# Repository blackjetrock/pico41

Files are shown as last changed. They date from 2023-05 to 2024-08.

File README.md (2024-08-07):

This project has been superseded by Tulip
=========================================

It is recommeded that the Tulip project is used instead of this one. It can be found here:

https://github.com/mjakuipers/TULIP-DevBoard

It has more features, by far. The only feature that it doesn't have is the key pressing, but it does have many more ways to enter programs...

Pico41
======

This is a PCB that can be attached to an HP41C (using wires soldered to the processor PCB of the HP41C) that allows:

* The HP41C bus to be examined and traced
* Data to be placed on the bus
* Keys on the keyboard to be pressed
* viewing of the display on an OLED display on the PCB

You can see what is happening on the bus just like a logic analyser. The tracing (and other interaction) is through the USB of the Pico.
You can emulate modules by putting appropriate words on the bus. Currently I have emulated a MATH module. Bank switched modules aren't supported, nor are RAM modules, but that is just a matter of code that I haven't done yet.
You can press keys on the keyboard, so can enter programs by pressing the appropriate keys. I have a script that converts program in text form and embeds the keypresses into the Pico program such that they can be played back in PRGM mode. Once entered like this the program can be SST'd automatically and checked against a listing that is also embedded in the Pio program.

RP Pico on HP41C bus, showing an emulated MATH module where one word has been altered:

IMAG3808

To Do
=====

It should be possible to emulate the display controller and use this Pico setup as a replacement for the display controller. For example a broken display controller should be replaceable by this program.
RAM should also be emulatable with more code.
Module code could be changed over USB rather than being embedded in the Pico code as it is now.

More Information
================

* https://youtu.be/KFQwrbWywjY
* https://youtu.be/kRxo2ekzvyg

This is a work in progress
==========================

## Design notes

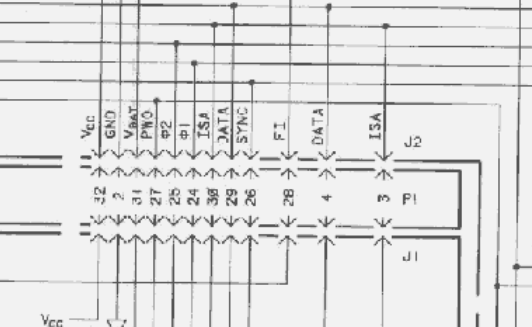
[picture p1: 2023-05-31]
pcb/Screenshot_20220318_142952.png

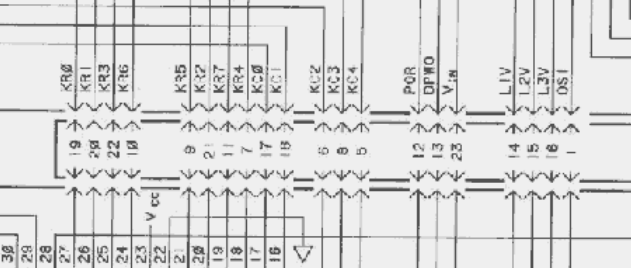
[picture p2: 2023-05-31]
pcb/Screenshot_20220318_143427.png

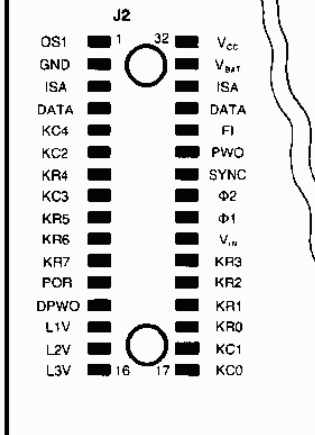
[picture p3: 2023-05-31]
pcb/Screenshot_20220318_143222.png

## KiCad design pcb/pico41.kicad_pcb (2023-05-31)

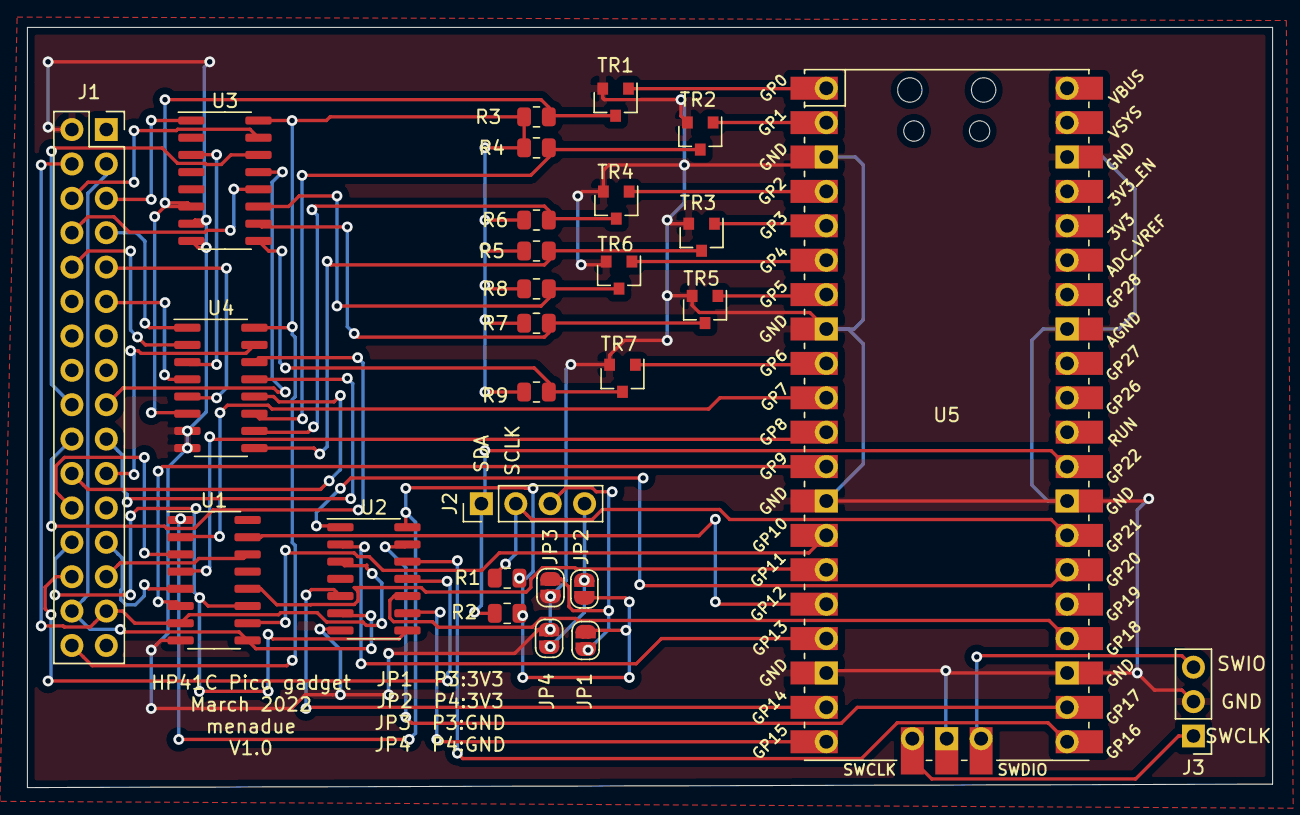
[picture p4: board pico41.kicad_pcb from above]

Board: 2 copper layers, 91.9 x 56.1 mm, 28 parts (0 on the bottom side), 57 nets.

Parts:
J1: Conn_02x16_Counter_Clockwise; PinSocket_2x16_P2.54mm_Vertical
J2: Conn_01x04_Female; PinHeader_1x04_P2.54mm_Vertical
J3: Conn_01x03_Female; PinHeader_1x03_P2.54mm_Vertical
JP1, JP2, JP3, JP4: Jumper_NO_Small; SolderJumper-2_P1.3mm_Open_RoundedPad1.0x1.5mm
R1, R2: 4k7; R_0805_2012Metric
R3, R4, R5, R6, R7, R8, R9: 10k; R_0805_2012Metric
TR1: Si2302; SOT-23
TR2, TR3, TR4, TR5, TR6, TR7: si2302; SOT-23
U1: 4050; SOIC-16_3.9x9.9mm_P1.27mm
U2: 74LS125; SOIC-14_3.9x8.7mm_P1.27mm
U3, U4: 4051; SOIC-16_3.9x9.9mm_P1.27mm
U5: Pico; RPi_Pico_SMD_TH

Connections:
3V3: JP1.1, JP2.1, R1.1, R2.1, U1.1, U2.14
DATA: J1.4, J1.29, U1.7, U2.3
FI: J1.28, U2.11
GND: J1.2, J3.2, JP3.1, JP4.1, TR1.2, TR2.2, TR3.2, TR4.2, TR5.2, TR6.2, TR7.2, U1.8, U2.7, U3.7, U3.8, U4.7, U4.8, U5.3, U5.8, U5.13, U5.18, U5.23, U5.28, U5.33, U5.38, U5.42
I2C_SCL: J2.2, R1.2, U5.27
I2C_SDA: J2.1, R2.2, U5.29
ISA: J1.3, J1.30, U1.9, U2.6
KB_INH: R3.2, TR1.3, U3.6, U4.6
KC0: J1.17, U3.13
KC1: J1.18, U3.14
KC2: J1.6, U3.15
KC3: J1.8, U3.12
KC4: J1.5, U3.1
KCA: R8.2, TR6.3, U3.11
KCB: R7.2, TR5.3, U3.10
KCC: R9.2, TR7.3, U3.9
KR0: J1.19, U4.13
KR1: J1.20, U4.14
KR2: J1.21, U4.15
KR3: J1.22, U4.12
KR4: J1.7, U4.1
KR5: J1.9, U4.5
KR6: J1.10, U4.2
KR7: J1.11, U4.4
KRA: R4.2, TR2.3, U4.11
KRB: R6.2, TR4.3, U4.10
KRC: R5.2, TR3.3, U4.9
unnamed: J2.3, JP1.2, JP3.2
unnamed: J2.4, JP2.2, JP4.2
unnamed: U3.3, U4.3
PHI1: J1.24, U1.3
PHI2: J1.25, U1.5
PWO: J1.27, U1.14
P_DATA: U1.6, U5.12
P_DATA_DRV: U2.2, U5.17
P_DATA_OE: U2.1, U5.26
P_FI_DRV: U2.12, U5.21
P_FI_OE: U2.13, U5.22
P_ISA: U1.10, U5.14
P_ISA_DRV: U2.5, U5.19
P_KB_INH: TR1.1, U5.1
P_KCA: TR6.1, U5.6
P_KCB: TR5.1, U5.7
P_KCC: TR7.1, U5.9
P_KRA: TR2.1, U5.2
P_KRB: TR4.1, U5.4
P_KRC: TR3.1, U5.5
P_PHI1: U1.2, U5.10
P_PHI2: U1.4, U5.11
P_PWO: U1.15, U5.16
P_SYNC: U1.12, U5.15
P_SYNC_DRV: U2.9, U5.20
P_SYNC_OE: U2.10, U5.24
SWCLK: J3.1, U5.41
SWIO: J3.3, U5.43
SYNC: J1.26, U1.11, U2.8
VCC: J1.32, R3.1, R4.1, R5.1, R6.1, R7.1, R8.1, R9.1, U3.16, U4.16

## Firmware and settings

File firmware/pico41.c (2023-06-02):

/*
 * HP41C monitoring and control from Pico
 *
 */

#include <ctype.h>
#include <stdio.h>
#include <string.h>
#include <stdlib.h>
#include <stdint.h>

#include "pico/stdlib.h"
//#include "hardware/i2c.h"
#include "hardware/gpio.h"
#include "hardware/pio.h"
#include "hardware/clocks.h"
#include "pico/multicore.h"

////////////////////////////////////////////////////////////////////////////////
//
// Configuration flags
//

#define CF_DUMP_DBG_DREGS  0
#define CF_DISPLAY_LCD     1
#define CF_DISPLAY_OLED    1
#define CF_DBG_DISP_ON     0
#define CF_DBG_SLCT        0
#define CF_DBG_DISP_INST   0
#define CF_USE_DISP_ON     1
#define CF_DBG_KEY         1

// Do we allow embedded ROM to be seen on the bus?

#define EMBED_8000_ROM     1
#define EMBED_9000_ROM     1

#define MAX_KWB  50

#define PRESS_DELAY_1   50
#define PRESS_DELAY_2   2000

////////////////////////////////////////////////////////////////////////////////
//
// GPIO Pins
//

const uint P_KB_INH            = 0;
const uint P_KRA               = 1;
const uint P_KRB               = 2;
const uint P_KRC               = 3;

const uint P_KCA               = 4;
const uint P_KCB               = 5;
const uint P_KCC               = 6;

const uint P_CLK1              = 7;
const uint P_CLK2              = 8;

const uint P_DATA              = 9;
const uint P_ISA               = 10;
const uint P_SYNC              = 11;
const uint P_PWO               = 12;
const uint P_DATA_DRV          = 13;
const uint P_ISA_DRV           = 14;
const uint P_SYNC_DRV          = 15;
const uint P_FI_DRV            = 16;
const uint P_FI_OE             = 17;
const uint P_SYNC_OE           = 18;
const uint P_ISA_OE            = 19;
const uint P_DATA_OE           = 20;

// For the OLED display
const uint SDA_PIN             = 22;
const uint SCL_PIN             = 21;

volatile int core1_command = 0;

#ifndef I2C_FUNCTIONS_H_
#define I2C_FUNCTIONS_H_

typedef unsigned char BYTE;

// I2C Port descriptor
typedef struct _I2C_PORT_DESC
{
  unsigned char sdaport;
  unsigned char sdabit;
  unsigned char sclport;
  unsigned char sclbit;
} I2C_PORT_DESC;


// Slave device descriptor
typedef struct _I2C_SLAVE_DESC
{
  I2C_PORT_DESC *port;             // Port the device is on
  unsigned char slave_7bit_addr;        // SLave address
} I2C_SLAVE_DESC;


// I2C functions
void i2c_release(I2C_PORT_DESC *port);
void i2c_delay(I2C_PORT_DESC *port);
void i2c_sda_low(I2C_PORT_DESC *port);
void i2c_sda_high(I2C_PORT_DESC *port);
void i2c_scl_low(I2C_PORT_DESC *port);
void i2c_scl_high(I2C_PORT_DESC *port);
void i2c_start(I2C_PORT_DESC *port);
void i2c_stop(I2C_PORT_DESC *port);
int i2c_send_byte(I2C_PORT_DESC *port, BYTE b);
int i2c_read_bytes(I2C_SLAVE_DESC *slave, int n, BYTE *data);
void i2c_send_bytes(I2C_SLAVE_DESC *slave, int n, BYTE *data);
#


#endif /* I2C_FUNCTIONS_H_ */

// Memory that emulates a pak
typedef unsigned char BYTE;
typedef void (*FPTR)(void);
typedef void (*CMD_FPTR)(char *cmd);


// Serial loop command structure
typedef struct
{
  char key;
  char *desc;
  FPTR fn;
} SERIAL_COMMAND;

////////////////////////////////////////////////////////////////////////////////
//
// HP41C stuff
//
////////////////////////////////////////////////////////////////////////////////

// Bus instructions
// Beware: These are in octal

#define INST_DISPLAY_OFF               01340
#define INST_DISPLAY_TOGGLE            01440
#define INST_COMPENSATION_INSTRUCTION  01774
#define INST_C_PFAD                    01760
#define INST_WRITE_ANNUNCIATORS        01360
#define INST_READ_ANNUNCIATORS         00570
#define INST_SRLAD                     00050
#define INST_SRLDB                     00150
#define INST_SRLDC                     00250
#define INST_SRLDAB                    00350
#define INST_SRLDABC                   00450
#define INST_SLLDAB                    00550
#define INST_SLLDABC                   00650
#define INST_SRSDA                     00750
#define INST_SRSDB                     01050
#define INST_SRSDC                     01150
#define INST_SLSDA                     01250
#define INST_SLSDB                     01350
#define INST_SRSDAB                    01450
#define INST_SLSDAB                    01550
#define INST_SRSDABC                   01650
#define INST_SLSDABC                   01750
#define INST_PRPH_SLCT                 01760
#define INST_RAM_SLCT                  01160

#define INST_FLLDA                     00070
#define INST_FLLDB                     00170
#define INST_FLLDC                     00270
#define INST_FLLDAB                    00370
#define INST_FLLDABC                   00470
#define INST_FLSDC                     00670
#define INST_FRSDA                     00770
#define INST_FRSDB                     01070
#define INST_FRSDC                     01170
#define INST_FLSDA                     01270
#define INST_FLSDB                     01370
#define INST_FRSDAB                    01470
#define INST_FLSDAB                    01570
#define INST_FRSDABC                   01670
#define INST_FLSDABC                   01770

// bank switching instructions
#define INST_ENBANK1                   0x100
#define INST_ENBANK2                   0x180
#define INST_ENBANK3                   0x140
#define INST_ENBANK4                   0x1C0

#define INST_ENROM1                    0x1500
#define INST_ENROM2                    0x1980
#define INST_ENROM3                    0x1D40
#define INST_ENROM4                    0x1C0



#define MASK_48_BIT    (0xFFFFFFFFFFFFL)

int display_ce = 0;
char dtext[40];

#define ROTATE_RIGHT(V) {uint64_t t = (V & 0xF); V >>= 4; V |= t<<44;}
#define  ROTATE_LEFT(V) {uint64_t t = (V & (0xFLL << 44)); V <<= 4; V |= t>>44;}

////////////////////////////////////////////////////////////////////////////////
//
// Prototypes
//
//

void process_bus(void);

////////////////////////////////////////////////////////////////////////////////

// Where embedded ROM image is located
#define LOW_EMBED_ROM_ADDR   0x8000
#define HIGH_EMBED_ROM_ADDR  0x8FFF

#define LOW_EMBED_ROM2_ADDR   0x9000
#define HIGH_EMBED_ROM2_ADDR  0x9FFF

// Do we drive ROM data?
int drive_data_flag = 0;

// The data we drive
int drive_data = 0;

// How many times have we driven ISA?
volatile int driven_isa = 0;
volatile int embed_seen = 0;
volatile int sync_count = 0;

char *embed_prog[] = {
		      // HP41C_EMBEDDED_PROG_START
"01 LBLGPHASE", "02 DEG", "03 XEQGJ0", "04 7.382647", "05 STO 03", "06 /", "07 INT", "08 STO 06", 
"09 ST* 03", "10 4", "11 MOD", "12 STO 04", "13 2", "14 STO 02", "15 XMY?", "16 ST- 02", 
"17 ST/ 02", "18 MOD", "19 STO 05", "20 221", "21 *", "22 RCL 02", "23 -", "24 407", 
"25 +", "26 RCL 06", "27 96.45423", "28 *", "29 21.6", "30 +", "31 STO 00", "32 SIN", 
"33 *", "34 RCL 06", "35 7.2763", "36 *", "37 2.6", "38 +", "39 STO 01", "40 SIN", 
"41 172", "42 RCL 02", "43 +", "44 *", "45 +", "46 RCL 05", "47 7", "48 *", 
"49 16", "50 -", "51 RCL 00", "52 ST+ X", "53 SIN", "54 *", "55 -", "56 RCL 05", 
"57 5", "58 -", "59 ST+ X", "60 RCL 06", "61 195.335", "62 *", "63 39", "64 -", 
"65 STO 02", "66 SIN", "67 *", "68 -", "69 RCL 05", "70 ST+ X", "71 7", "72 -", 
"73 RCL 00", "74 RCL 01", "75 -", "76 SIN", "77 *", "78 +", "79 RCL 05", "80 7", 
"81 *", "82 5", "83 +", "84 RCL 00", "85 RCL 01", "86 +", "87 SIN", "88 *", 
"89 +", "90 RCL 01", "91 ST+ X", "92 SIN", "93 ST+ X", "94 +", "95 RCL 05", "96 RCL 00", 
"97 RCL 02", "98 -", "99 SIN", "100 ST* Y", "101 +", "102 +", "103 RCL 04", "104 90", 
"105 *", "106 SIN", "107 3", "108 *", "109 +", "110 5598", "111 +", "112 E3", 
"113 /", "114 RCL 03", "115 +", "116 INT", "117 LASTX", "118 FRC", "119 X<0?", "120 DSE Y", 
"121 """, "122 24", "123 ST* Y", "124 MOD", "125 HMS", "126 X<>Y", "127 XEQGDT", "128 RCL 04", 

// HP41C_EMBEDDED_PROG_END
};

char *embed_keys[] = {
// HP41C_EMBEDDED_KEYS_START
"SHIFT", "STO", "ALPHA", "P", "H", "A", "S", "E", 
"ALPHA", "XEQ", "ALPHA", "D", "E", "G", "ALPHA", "XEQ", 
"ALPHA", "J", "SHIFT", "0", "ALPHA", "7", ".", "3", 
"8", "2", "6", "4", "7", "STO", "0", "3", 
"/", "XEQ", "ALPHA", "I", "N", "T", "ALPHA", "STO", 
"0", "6", "STO", "*", "0", "3", "4", "XEQ", 
"ALPHA", "M", "O", "D", "ALPHA", "STO", "0", "4", 
"2", "STO", "0", "2", "XEQ", "ALPHA", "X", "SHIFT", 
"H", "Y", "3", "ALPHA", "STO", "-", "0", "2", 
"STO", "/", "0", "2", "XEQ", "ALPHA", "M", "O", 
"D", "ALPHA", "STO", "0", "5", "2", "2", "1", 
"*", "RCL", "0", "2", "-", "4", "0", "7", 
"+", "RCL", "0", "6", "9", "6", ".", "4", 
"5", "4", "2", "3", "*", "2", "1", ".", 
"6", "+", "STO", "0", "0", "SIN", "*", "RCL", 
"0", "6", "7", ".", "2", "7", "6", "3", 
"*", "2", ".", "6", "+", "STO", "0", "1", 
"SIN", "1", "7", "2", "RCL", "0", "2", "+", 
"*", "+", "RCL", "0", "5", "7", "*", "1", 
"6", "-", "RCL", "0", "0", "STO", "+", ".", 
"X", "SIN", "*", "-", "RCL", "0", "5", "5", 
"-", "STO", "+", ".", "X", "RCL", "0", "6", 
"1", "9", "5", ".", "3", "3", "5", "*", 
"3", "9", "-", "STO", "0", "2", "SIN", "*", 
"-", "RCL", "0", "5", "STO", "+", ".", "X", 
"7", "-", "RCL", "0", "0", "RCL", "0", "1", 
"-", "SIN", "*", "+", "RCL", "0", "5", "7", 
"*", "5", "+", "RCL", "0", "0", "RCL", "0", 
"1", "+", "SIN", "*", "+", "RCL", "0", "1", 
"STO", "+", ".", "X", "SIN", "STO", "+", ".", 
"X", "+", "RCL", "0", "5", "RCL", "0", "0", 
"RCL", "0", "2", "-", "SIN", "STO", "*", ".", 
"Y", "+", "+", "RCL", "0", "4", "9", "0", 
"*", "SIN", "3", "*", "+", "5", "5", "9", 
"8", "+", "1", "EEX", "3", "/", "RCL", "0", 
"3", "+", "XEQ", "ALPHA", "I", "N", "T", "ALPHA", 
"XEQ", "ALPHA", "L", "A", "S", "T", "X", "ALPHA", 
"XEQ", "ALPHA", "F", "R", "C", "ALPHA", "XEQ", "ALPHA", 
"X", "SHIFT", "I", "SHIFT", "0", "3", "ALPHA", "XEQ", 
"ALPHA", "D", "S", "E", "ALPHA", ".", "Y", "XEQ", 
"ALPHA", "N", "O", "P", "ALPHA", "2", "4", "STO", 
"*", ".", "Y", "XEQ", "ALPHA", "M", "O", "D", 
"ALPHA", "XEQ", "ALPHA", "H", "M", "S", "ALPHA", "X<>Y", 
"XEQ", "ALPHA", "D", "T", "ALPHA", "RCL", "0", "4", 

// HP41C_EMBEDDED_KEYS_END
};

// Byte grabber keystrokes
char *byte_grabber_keys[] =
  {
#if 1
   "SHIFT","XEQ", "ALPHA", "SHIFT", "+", "ALPHA", "LN",
   "WAIT1",
   "SHIFT","XEQ", "ALPHA", "D", "E", "L", "ALPHA", "LOG",
   "WAIT1",
#endif   
   "PRGM",
   "WAIT1",
   "SHIFT",
   "WAIT1",
   "ENTER",
   "WAIT1",
   "1",
   "WAIT2",
   "R/S",
   "ALPHA",
   "<-",
   "ALPHA",
   "SHIFT", "RCL", ".", "0", "0", "5",
#if 0
   "USER",
   "LOG", "0", "0", "3",
   "ALPHA",
   "3", "A", "A", "A", "A", "A", "A",
   "PRGM", "ALPHA",
   "SHIFT", "RCL", ".", "."
#endif
  };

// Embedded ROM images

int embed_zenrom_rom[] = {
		   
0x0005,0x000d,0x0000,0x0028,0x0005,0x0079,0x0005,0x0090,0x0005,0x0010,0x0004,0x00aa,0x0005,0x0069,0x0005,0x00cc,
0x0005,0x0029,0x0004,0x00ce,0x0004,0x00d6,0x0004,0x00de,0x0003,0x0047,0x0005,0x0042,0x0000,0x0000,0x0082,0x0033,
0x0020,0x000d,0x000f,0x0012,0x000e,0x0005,0x001a,0x002d,0x03e0,0x005e,0x027e,0x0398,0x00ee,0x004e,0x029c,0x0210,
0x0158,0x010e,0x03f8,0x03b0,0x010e,0x0198,0x028c,0x01af,0x034e,0x01a3,0x02ae,0x010e,0x03f8,0x03b0,0x03e8,0x0198,
0x010e,0x02b8,0x03b0,0x010e,0x03b8,0x02bc,0x03d8,0x0384,0x034e,0x0013,0x0388,0x03d8,0x02bc,0x03a8,0x0198,0x02ae,
0x010e,0x02b8,0x03b0,0x02a8,0x00ee,0x0358,0x02fe,0x00e1,0x003e,0x023e,0x01df,0x03b8,0x031c,0x0171,0x001c,0x0278,
0x0325,0x0050,0x0268,0x02b8,0x003c,0x0106,0x0130,0x000f,0x036a,0x002f,0x0229,0x001a,0x007b,0x0153,0x0086,0x03d9,
0x001c,0x03dd,0x00ac,0x0149,0x0024,0x0278,0x00e0,0x02dc,0x00a0,0x0171,0x003e,0x034e,0x00df,0x010e,0x03f8,0x0370,
0x03e8,0x02b8,0x010e,0x0198,0x00ee,0x03b8,0x02bc,0x03d8,0x00ee,0x038c,0x0027,0x02ae,0x03b0,0x0017,0x0370,0x02a8,
0x00ce,0x0384,0x03d8,0x02bc,0x03a8,0x0171,0x001c,0x004e,0x01b0,0x0170,0x010e,0x015c,0x0010,0x0350,0x03d0,0x0290,
0x036e,0x01d7,0x0020,0x00b0,0x03cd,0x009c,0x0049,0x0036,0x0130,0x0020,0x03a8,0x03a8,0x03a8,0x00e6,0x036d,0x007c,
0x0106,0x001e,0x0130,0x0054,0x0366,0x0025,0x003a,0x02dc,0x00d0,0x0130,0x005b,0x017e,0x0266,0x0366,0x03bb,0x037e,
0x03df,0x02dc,0x0290,0x0130,0x004c,0x017e,0x0366,0x0373,0x0226,0x017e,0x037e,0x03df,0x0366,0x002f,0x0130,0x007f,
0x0106,0x0323,0x0130,0x0040,0x017e,0x003f,0x0226,0x0366,0x03e7,0x0126,0x02db,0x00d3,0x0086,0x0130,0x0007,0x0106,
0x0149,0x0024,0x03f8,0x003c,0x03b0,0x0366,0x002b,0x03d9,0x001c,0x0079,0x003a,0x0066,0x0130,0x002c,0x0366,0x03c7,
0x02b8,0x003c,0x010e,0x0265,0x0036,0x009c,0x0350,0x0090,0x0090,0x036e,0x00d7,0x02b8,0x003c,0x0056,0x02e6,0x003b,
0x03f8,0x003c,0x03d8,0x038c,0x002f,0x03d8,0x00b0,0x03cd,0x009e,0x0304,0x0204,0x03d8,0x01bc,0x03e8,0x0020,0x00d1,
0x0030,0x0000,0x03ad,0x0032,0x009c,0x0350,0x0310,0x0110,0x036e,0x0087,0x0020,0x00b0,0x03cd,0x009c,0x0049,0x0036,
0x005c,0x0210,0x00d0,0x011a,0x0220,0x037a,0x0315,0x0037,0x00cb,0x009c,0x0310,0x0390,0x0350,0x036e,0x012f,0x0020,
0x00b0,0x03cd,0x009c,0x0049,0x0036,0x028c,0x03cd,0x0037,0x005c,0x0210,0x00d0,0x011a,0x031c,0x0220,0x037a,0x03b9,
0x0033,0x0130,0x0031,0x03e8,0x0121,0x0038,0x0053,0x004c,0x0351,0x0037,0x000c,0x00bd,0x0039,0x0265,0x0020,0x03ab,
0x03b8,0x03ad,0x0032,0x028c,0x01bf,0x0130,0x0308,0x0236,0x0106,0x03b8,0x03b0,0x0366,0x0033,0x03b8,0x0358,0x00b0,
0x03cd,0x009e,0x004e,0x026e,0x0130,0x0091,0x0276,0x023c,0x0056,0x010e,0x037c,0x0130,0x00af,0x0276,0x023c,0x00ee,
0x0238,0x01bc,0x0358,0x0278,0x030c,0x0017,0x006e,0x036e,0x032f,0x038c,0x031f,0x030c,0x0359,0x0026,0x00ee,0x0268,
0x0149,0x00a4,0x0019,0x008c,0x004e,0x0270,0x0238,0x01bc,0x0358,0x0299,0x00b6,0x009c,0x004e,0x0390,0x0390,0x0210,
0x036e,0x01f7,0x0020,0x00b0,0x03cd,0x009c,0x03d9,0x003a,0x031c,0x0149,0x0024,0x0220,0x003c,0x0106,0x0130,0x00c6,
0x036a,0x007f,0x03b8,0x02bc,0x03d8,0x038c,0x001f,0x0388,0x0013,0x0384,0x03d8,0x02bc,0x016d,0x001c,0x0019,0x003e,
0x0278,0x010e,0x0238,0x034e,0x001f,0x005e,0x0228,0x00ee,0x03b8,0x023c,0x008c,0x01bb,0x03d8,0x038c,0x0097,0x03d8,
0x034e,0x0027,0x030c,0x0019,0x003f,0x03d8,0x00e6,0x03b8,0x0358,0x0284,0x0398,0x03a8,0x0341,0x008c,0x002d,0x0183,
0x03d9,0x001c,0x0130,0x001f,0x03e8,0x03dd,0x00ac,0x0349,0x008c,0x02a1,0x0033,0x00f5,0x0030,0x0000,0x0019,0x003e,
0x00f5,0x0030,0x0000,0x0149,0x0024,0x0278,0x02ee,0x0027,0x0238,0x023e,0x0228,0x0125,0x001c,0x0198,0x0106,0x031c,
0x0085,0x003e,0x00bc,0x03d8,0x038c,0x0027,0x03d8,0x03a5,0x003a,0x03d8,0x0349,0x008c,0x0263,0x0373,0x03cb,0x03b8,
0x023c,0x03d8,0x038c,0x0113,0x004e,0x0130,0x0300,0x037c,0x03cc,0x003f,0x026e,0x03eb,0x000c,0x03bf,0x0321,0x0046,
0x0220,0x003c,0x0106,0x0130,0x00c4,0x0366,0x007f,0x03b8,0x0358,0x0349,0x008c,0x02a1,0x00d3,0x000c,0x01fb,0x0278,
0x023e,0x0015,0x00ba,0x0001,0x00ba,0x03b8,0x0358,0x02bc,0x03d8,0x038c,0x002f,0x03d8,0x00b0,0x03cd,0x009e,0x03d8,
0x0349,0x008c,0x0263,0x001b,0x0015,0x0032,0x0106,0x039c,0x0058,0x0125,0x001c,0x03b8,0x01f6,0x01f6,0x007f,0x029d,
0x0058,0x0358,0x000c,0x022d,0x00bb,0x013c,0x03d8,0x0388,0x03d8,0x017c,0x03a8,0x0209,0x00ba,0x000c,0x0053,0x0278,
0x023e,0x00b5,0x00ba,0x0265,0x0020,0x010c,0x026b,0x004b,0x010c,0x0221,0x00b7,0x0039,0x00b4,0x0108,0x0041,0x00b0,
0x031d,0x0002,0x03d8,0x0108,0x004e,0x0130,0x0300,0x037c,0x011a,0x03cc,0x0057,0x026e,0x03eb,0x03b8,0x023c,0x03d8,
0x000c,0x038f,0x0321,0x0046,0x004e,0x0220,0x033c,0x0116,0x01f6,0x03cf,0x00b6,0x03c6,0x03c6,0x0106,0x01e6,0x01e6,
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
};

int embed_rom[] = {
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
int main(void)
{
  
  ////////////////////////////////////////////////////////////////////////////////
  //
  // Overclock as needed
  //
  ////////////////////////////////////////////////////////////////////////////////
  
  //#define OVERCLOCK 135000
  //#define OVERCLOCK 200000
#define OVERCLOCK 270000
  //#define OVERCLOCK 360000
  
#if OVERCLOCK > 270000
  /* Above this speed needs increased voltage */
  vreg_set_voltage(VREG_VOLTAGE_1_20);
  sleep_ms(1000);
#endif
  
  /* Overclock */
  set_sys_clock_khz( OVERCLOCK, 1 );

  stdio_init_all();

  sleep_ms(2000);

  printf("\n*************");
  printf("\n*  Pico 41  *");
  printf("\n*************");
  printf("\n");
  
  printf("\nSetting up OLED...");
  
   // Set up OLED display
  i2c_init(&i2c_bus_0);
    
  oled_setup(&oled0);
  
  oled_set_xy(&oled0, 0, 8);
  oled_display_string(&oled0, "Pico41");



#if 1
  printf("\nSetting up kbd...");
  kb_init();

  printf("\nSetting up drv...");
  drv_init();

  printf("\nSetting up bus...");
  bus_init();
#endif
  
  //multicore_launch_core1(core1_main2);

#if 0
  // Sit in a loop processing things
  while(1)
    {
      
      // Synchronise to clk1 edge
      while(1)
	{
	  // get GPIO states
	  gpios2 = sio_hw->gpio_in;
	  
	  clk2 = gpios2 & (1<<P_CLK2);
	  
	  if( (last_clk2==0) && (clk2!=0) )
	    {
	      break;
	    }
	  last_clk2 = clk2;
	}
      
      // Rising edge of clk1 has occurred
      bitnum++;
      if( bitnum > 55 )
	{
	  bitnum = 0;
	}
      
      //      buffer[buffer_i] = gpio_get(P_CLK1);
      buffer[buffer_i++] = gpios2 & ((1 << P_CLK1) |(1 << P_CLK2) | (1<<P_SYNC) | (1<<P_DATA)| (1<<P_ISA));
      
      isa  = gpios2 & (1<<P_ISA);
      data = gpios2 & (1<<P_DATA);
      sync = gpios2 & (1<<P_SYNC);
      
      if( (last_sync!=0) && (sync==0) )
	{
	  bitnum = 54;
	}

      if( bitnum == 0 )
	{
	  // End of instruction so store and reset  data
	  value_list[value_list_i++] = data_value;
	  value_list_i &= (NUM_VL -1);
	  data_value = 0;
	  isa_list[isa_list_i++] = isa_value;
	  isa_list_i &= (NUM_VL -1);
	  isa_value = 0;
	}
      
      // Shift data in
      //      data_value >>= 1;
      if( data )
	{
	  data_value |= ((uint64_t)1)<<bitnum;
	}

      // Shift ISA in
      //isa_value >>= 1;
      if( isa )
	{
	  isa_value |= ((uint64_t)1)<<bitnum;
	}
      
      last_sync = sync;
      
      if( buffer_i >= NUMB)
	{
	  buffer_i = 0;
	}
      //      buffer_i = (buffer_i+1) % NUMB;
    }
#else

#if 0  
  // Turn our drive of the bus off
  drv_init();
#endif
  
  multicore_launch_core1(core1_main_3);
  //  irq_set_mask_enabled(0xffff, false);

  printf("\nReady\n");
  
  // Sit in a loop
  while(1)
    {
      process_bus();

      // Update the USB CLI
      serial_loop();
    }
  
#endif
}
